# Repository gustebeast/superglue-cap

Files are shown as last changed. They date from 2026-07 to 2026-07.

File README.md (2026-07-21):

# superglue-cap

Parametric replacement **dispenser nozzle + sealing cap** for superglue
bottles, modelled in [CadQuery](https://cadquery.readthedocs.io/) with the
shared [`cadkit`](https://github.com/gustebeast/cadkit) utilities (vendored
under `cadkit/` via git subtree).

The stock dispenser tips on cyanoacrylate bottles clog and shear off; this
replaces them with a printable two-piece set:

- **Nozzle** (~50 mm tall) — screws onto the bottle's neck thread and
  funnels glue through a single continuous internal cone (Ø7.3 throat →
  Ø0.8 orifice, no kinks for glue to pool in) to a slender dispensing tip.
- **Cap** — a 1.6 mm conical shell that follows the nozzle. It closes in a
  **half turn** (2-start, 8 mm lead thread), its flat mouth rim lands on the
  nozzle's flat shoulder, and a 45° internal pocket wedges onto the nozzle's
  tip rim with 0.15 mm of preload — thread torque loads both contacts.

Two bottle variants share all of the code and the same cap — only the
bottle-thread socket differs:

| Variant | Socket bore | Ridge-tip ID | Pitch | Engagement | Status |
|---|---|---|---|---|---|
| `macbeath` | Ø15.3 | Ø13.7 | 2 mm | 11.5 mm | print-validated |
| `loctite`  | Ø18.0 | Ø16.0 | 3 mm | 11.0 mm | fit pending — print its coupon first |

Adding a bottle = adding one `BottleSpec` line in `src/dimensions.py` — or
just using the web generator below with your own measurements.

## Web generator

[`docs/`](docs/) is a browser-based generator (same idea as the
[pantorouter template generator](https://github.com/gustebeast/pantorouter-template-generator)):
measure your bottle's thread with calipers — the page has diagrams for each
measurement — hit Generate, and download STEP/STL for a nozzle, cap, and
thread-fit test piece matched to your bottle. All geometry is built locally in the
browser via [replicad](https://replicad.xyz); nothing is uploaded. The JS
geometry mirrors `src/` constant-for-constant — keep them in sync.

To preview locally (a real HTTP server is needed for the WASM kernel):

```sh
py -3.12 -m http.server 8080 -d docs
# open http://localhost:8080
```

To publish: enable GitHub Pages for the repo, source "main branch /docs".

## Printing

All parts: **flat mouth face down, axis vertical, no supports.**
PETG or PLA, 0.4 mm nozzle, 0.2 mm layers, 3+ walls. Enable your slicer's
elephant-foot compensation (the bottoms are deliberately square for bed
adhesion, and thread ridges reach the first layer). The Ø0.8 orifice prints
tight at 0.4 mm — clear it with a pin, or slice the nozzle at 0.2 mm.

Print the `test_<variant>_socket.step` **coupon** (a few minutes of plastic)
and spin it onto your bottle before committing to the full nozzle.

Note: cyanoacrylate bonds PETG/PLA, so treat the nozzle as a consumable —
or print it in PP, which CA barely sticks to. A PTFE dry-film spray in the
channel makes cured clogs removable.

## Building from source

Requires Python 3.10–3.12 with `cadquery` installed.

```
py -3.12 -m src.build              # all STEPs + assembly.step (+ FreeCAD viewer)
py -3.12 -m src.build --list      # part names
py -3.12 -m src.build --part cap  # one part
py -3.12 -m tools.check_overlaps  # collision gate (0 = clean)
```

`View Assembly.cmd` opens the last-built assembly in FreeCAD (Windows).

## Layout

```
src/
  dimensions.py    every constant + the BottleSpec variants (start here)
  thread_socket.py the asymmetric (buttress) bottle-thread socket + probes
  nozzle.py        nozzle builder (per BottleSpec)
  cap.py           the shared cap builder
  grip.py          grip-rib helper
  build.py         build/export/assembly entry point
tools/
  check_overlaps.py  interpenetration gate over the seated assembly
cadkit/            vendored shared library (threads, export, viewer, ...)
```

Two thread systems live here, and both are probe-gated at build time (a
solid/void march along each helix — OCCT fails silently, so the build fails
loudly instead):

- the **bottle socket** is a project-local asymmetric profile — a 45°
  self-supporting ridge underside with a steep top flank — because these
  bottles' depth-to-pitch ratios are impossible for a symmetric 45° FDM
  thread;
- the **nozzle↔cap** joint uses `cadkit.threads`' multistart family
  (upstreamed from this project), the print-proven Ø13/Ø11 profile on two
  8 mm-lead helices.

## License

[CERN-OHL-S v2](https://cern-ohl.web.cern.ch/) (strongly reciprocal) —
models, code, and site. Use, modify, and sell freely; distribute sources
of derivatives under the same licence.

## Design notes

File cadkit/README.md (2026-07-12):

# cadkit

Small, project-agnostic helpers for **parametric 3D-printing with CadQuery** — the
shared code behind a set of printable-hardware projects. Vendored into each project via
`git subtree`, so every project repo stays self-contained.

## Layout

```
cadkit/
  fasteners.py       M2/M4 hole + heat-set-insert geometry (self-tap now, insert later);
                     one FastenerSpec API, print-undersize aware
  threads.py         self-supporting 45° FDM screw threads (read THREADS_README.md first)
  joinery.py         printable mortise-and-tenon slide joints (read JOINERY_README.md)
  step_export.py     export_step(obj, path) — names the STEP product after the file
  overlap_check.py   parallel interpenetration gate (wrap in tools/check_overlaps.py)
  cq_colors.py       hex / 0..255 / name -> cq.Color, for baking colours into a STEP
  freecad/           OPTIONAL FreeCAD viewer hub (isolated so the core needs no FreeCAD)
    __init__.py        `from cadkit.freecad import show`
  tools/
    agent_sync.py    dev-only multi-agent git-worktree coordination CLI (run as a script)
```

The **core** modules depend only on CadQuery/OCP — no FreeCAD. The FreeCAD-specific
viewer lives in `cadkit.freecad` and is opt-in; `show()` never raises, so viewer trouble
can't break a build.

## Use

```python
from cadkit.fasteners import cut_anchor, M2, M4
from cadkit.threads import cut_thread, threaded_rod
from cadkit.joinery import arrow_tenon, arrow_mortise
from cadkit.step_export import export_step
from cadkit.overlap_check import run
from cadkit import cq_colors
from cadkit.freecad import show          # optional; opens/refreshes a FreeCAD viewer tab
```

A project vendors cadkit at its repo root and runs its build via `python -m` from there,
so `cadkit` is importable with no path hack.

## Vendoring into a project

```
git remote add cadkit https://github.com/gustebeast/cadkit
git subtree add  --prefix=cadkit cadkit main --squash    # first time
git subtree pull --prefix=cadkit cadkit main --squash    # to update later
```

## Changing cadkit — you MUST propagate to every consumer

cadkit is **vendored** (copied) into each project, so the copies **drift** the
moment the canonical repo changes — nothing forces them identical. Therefore a
cadkit change is not *done* when you commit it; it is done when every consumer
project has been re-pulled. **Never edit a project's vendored `cadkit/` in place** —
edit the canonical repo, then propagate.

The whole process is one command — **run it from the standalone canonical cadkit
checkout, after committing your change there** (it refuses to run from a project's
vendored copy):

```
py -3.12 tools/propagate.py        # pushes canonical, then re-pulls into every consumer
```

It pushes the canonical to its upstream (one source of truth), auto-discovers
every sibling project that vendors cadkit, and re-pulls the subtree into each.
A project with a **dirty** working tree is **skipped** (never auto-stashed) and
reported — commit or stash there, then re-run. The exit code is the number of
consumers *not* in sync, so `propagate.py` doubles as a gate: **0 means every
project is current.** Use `--dry-run` to preview, `--no-push` to pull only.

(The manual equivalent, per project, is `git fetch cadkit main &&
git subtree pull --prefix=cadkit cadkit main --squash` — but do not hand-run it
across N repos; that is exactly the step people forget, which is what drift is.)

See `THREADS_README.md` and `JOINERY_README.md` before changing threads or joinery —
both encode FDM-specific rules that fail silently if broken.

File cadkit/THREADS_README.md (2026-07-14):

# `threads.py` — self-supporting 45° screw threads in CadQuery, the reliable way

Cutting a printable helical thread in CadQuery / OpenCASCADE (OCCT) is a known
pain — the kernel fails **silently and weirdly**, returning a smooth cylinder, a
half-filled rod, zero solids, or hanging for minutes, all with *no error*. This
module encodes every workaround we had to find. Import it and move on with your
life; read this if you need to change it.

```python
from cadkit.threads import threaded_rod, cut_thread

# short rods / nut cutters / test coupons:
nut_cutter = threaded_rod(minor_d=11, major_d=13, pitch=4, length=20)
piston = body.cut(nut_cutter)               # -> internal thread in the bore

# a long screw: build a SMOOTH blank, subtract the thread LAST, mill any flat AFTER:
blank = crest_cyl.union(shaft).union(head)  # all smooth
screw = cut_thread(blank, minor_d=11, major_d=13, pitch=4, length=146, z=64)
screw = screw.cut(flat_box)                 # flat AFTER the thread
```

## What the thread looks like

A single-start **45° trapezoidal** thread — symmetric flanks at 45°, with small
flats at the crest and root:

- **Self-supporting.** Because no flank exceeds 45°, an internal thread (a nut)
  prints with its **axis vertical** and needs *no support* in the bore. The screw
  side-prints cleanly too. This is the standard FDM "self-supporting thread".
- **Depth ≤ pitch/2.** 45° flanks need `(major-minor)/2 ≤ pitch/2`. E.g. pitch 4 →
  depth ≤ 2; we run Ø13/Ø11 = depth 1.0 with 1.0 mm flats for margin.
- **Cut, never grown.** The thread is helical **valleys cut out of a solid
  crest-diameter blank**. Do *not* build a thread ridge and union it onto a core —
  OCCT drops the core and you get a hollow spring that still reports `solids == 1`.

## Sideways (horizontal-axis) female threads — `teardrop_thread_cutter`

A female thread whose axis prints **horizontal** (a screw hole in a part that lies flat
on the bed) can't use a plain round bore: the bore's top arc is an unsupported overhang
that **sags into a rough, tight thread**. `teardrop_thread_cutter` is the cutter to
subtract for any horizontally-printed threaded hole. **Print-tested clean** (Ø6 cap
screw, PETG — see the clearance table). Orient the part so **print-up is +Y**.

It returns a threaded rod **unioned** with a self-supporting **hexagon peak** on its +Y
side — subtract it, then `clean=False` / don't heal (same thread rules):

```python
from threads import teardrop_thread_cutter
cutter = teardrop_thread_cutter(minor_d, major_d, pitch, engage_len,
                                z=z0, peak_h=..., over_lo=0.0)   # blind end flush
part = part.cut(cutter.translate((x, y, 0)), clean=False)
```

- **Keep the FULL round bore — never slice its top off.** A round screw needs that top;
  a secant/gable cut that removes it leaves solid material where the screw's upper half
  must go and the screw won't seat. The peak is *added* above the full bore, not carved
  out of it. (Cost a build to learn — the "gable" looked right and blocked the screw.)
- **The peak is a HEXAGON, not a plain teardrop.** The transition from round threads to
  the smooth attic runs on **45° planes** (the lines `y = ±x`, matching the thread's 45°
  flank), so the top-wedge ridges are cut **clean**. A horizontal base (plain
  trapezoid/teardrop) slices each tooth on a flat → thin sub-nozzle **slivers**. The
  hexagon's left/right corners (a +45° meeting a −45° edge) are 90°.
- The round lower ~270° stays threaded; the top ~90° is given up to the peak (same trade
  as the drive screw's milled flat). It grips fine.
- `peak_h` truncates the tip to a short flat **bridge** when the wall above the hole is
  thin (a small sag on a <2 mm bridge is harmless). `over_lo`/`over_hi` set the peak
  overshoot per end: **keep it at the MOUTH** (opens the teardrop cleanly where the
  socket exits into air), **zero it at a BLIND end** — else the hexagon drills a pocket
  deeper than the round bore and you get two visible hole depths.
- The thread **runs out** at each end through `threaded_rod`'s conical lead-in, so the
  last tooth dissolves into a smooth cone instead of a thin feather — don't "fix" it.

## Multi-start (quarter-turn) threads — `multistart_rod` / `cut_multistart_thread`

A cap that seals in a **90° turn** needs a multi-start thread: `starts` parallel
helices, each advancing `lead = spacing·starts` per turn (4-start × 4 mm spacing →
4 mm per quarter turn). The trick that keeps this inside everything already proven:
**the cross-section derives from `spacing`** (the caliper ridge-to-ridge distance),
so a 4-start spacing-4 thread is locally IDENTICAL to the pitch-4 single-start
profile — only the helix steepens (~24° lead angle at Ø12).

```python
from cadkit.threads import multistart_rod, cut_multistart_thread

# male collar on the nozzle (0.6 mm diametral clearance taken off the male):
nozzle = cut_multistart_thread(smooth_nozzle, minor_d=10.4, major_d=12.4,
                               spacing=4, starts=4, length=6, z=collar_z)
# female nut in the cap (cutter at NOMINAL size):
cap = cap_body.cut(multistart_rod(11, 13, spacing=4, starts=4,
                                  length=6.5, z=-0.5), clean=False)
```

Multi-start-specific rules (each verified by crest probes in `superglue-cap`):

- **Never reuse `thread_segments` for multi-start** — its flats derive from the
  full per-helix pitch; at lead 16 the valleys come out 7 mm wide and the starts
  erase each other. `_valley_profile(minor, major, spacing)` is the shared quad.
- **Different starts must not overlap**: valley width at the overshoot < spacing
  (checked, raises). Same 3.6-vs-4.0 margin as the proven pitch-4 profile.
- **Sweeps are still whole turns — of the LEAD.** A short band (a 6 mm collar on
  a 16 mm lead) is covered by ONE full-turn sweep based at the band and RUNNING
  OUT past it: upward it must exit into air or a sub-minor-Ø section; downward it
  leaves a shallow helical notch (~a groove half-width) in whatever shoulder is
  there — keep that notch inside the mating rim's clearance Ø.
- **Sweeps may pass THROUGH blank faces** (the nut cutter's rod is shorter than
  one lead; the sweeps enter below and exit above it, ending in air). Rule 5's
  killer is a sweep **ending at** a blank face, not passing through one.
- **A healthy N-start thread probes IDENTICALLY at θ and θ+360°/N** (and for even
  N, at θ+180°) — that symmetry is a quick sanity signature, not a bug.
- Self-locking is weak at steep leads (24° > friction angle): a quarter-turn cap
  holds shut by seal friction. If it backs off, add a detent, don't flatten the lead.

First deployment: superglue-cap nozzle↔cap (Ø13/Ø11, spacing 4, 4-start, 0.6 mm
diametral clearance off the male, 0.4 nozzle). **Print-fit pending** — record the
verdict in the clearance table below when it's in.

## Clearance (print-tested)

Thread clearance is print-dependent — nozzle width, layer height, orientation, and
material all change how much slop you need, so **record what you measure**. Tip: when
the nut is already printed, put the clearance on the **screw** side (shrink the screw,
keep the nut cutter fixed) so you only reprint the screw.

Tested combinations (append as you find them):

| thread | clearance (diametral) | nut / socket print | screw print | nozzle | layer | result |
|---|---|---|---|---|---|---|
| Ø13/Ø11, pitch 4, 45°, depth 1.0 | **0.8 mm** (0.4/side) | axis vertical (self-supporting bore) | on its side, on the flat | 0.8 mm | 0.24 mm | threads fast & easy, a bit loose — fine when the nut is well supported in X/Y |
| Ø6/Ø4.4, pitch 3.5, 45°, **teardrop socket** | **0.4 mm** (0.2/side) | **horizontal axis, hexagon peak up** | on its side, on the flat | 0.8 mm | — | **PETG**: turns in/out easily, on the **loose** side — a good friction hold for a cap here; go **0.2–0.3** for a snugger fit on other projects |

## The rules (each one cost a build)

Every violation below is a **silent** failure. The only reliable detector is a
**crest solid/void probe**: march up Z at `r = major/2 - 0.15` and classify
point-in-solid; a real thread alternates `#....#....#`, a broken one is all `#`
(smooth/filled) or throws (0 solids). Never trust the eye or `solids == 1`.

1. **Groove profile must be a 4-point quad.** A 6-point profile (e.g. a "capped"
   valley) makes the swept cutter's `.cut()` wipe the whole part to 0 solids.

2. **Depth ≤ pitch/2**, and keep margin — a valley near `pitch/2` wide, tilted by
   the helix lead angle (isFrenet), self-overlaps turn-to-turn into an invalid
   cutter that no-ops.

3. **A single sweep is clean only to ~100 mm.** Longer, and the sweep+cut wipes the
   part (0 solids). So **tile** the length in short **segments** (`_SEG_LEN = 72`).

4. **Segments must ABUT, never overlap.** Cutting a helix cutter that overlaps an
   already-cut region **silently no-ops** — so every segment after the first leaves
   its span *filled*. (Unioning the overlapping segments into one cutter first fills
   too.) Abut them and **phase-align** each (`rotate 360°·z0/pitch`) so the valleys
   line up into one continuous single-start thread across the seams. Pick a segment
   length that's a multiple of the pitch so the joins land on a tooth edge (phase 0).

5. **Sweep height AND blank height must be whole turns** (multiples of pitch). A
   *partial* final turn wipes the part; so does a sweep that reaches the top of a
   non-whole-turn cylinder. `threaded_rod` rounds its rod **up** to a whole turn;
   `cut_thread` rounds the span **down** so the thread ends *inside* the blank —
   overshooting up into a smaller-Ø shaft grazes it and leaves a thin degenerate
   face at the thread top (a visible "rectangle" artifact).

6. **Cut the thread LAST and ALONE.** Every boolean on the finished (many-face)
   thread is slow — unions/cuts that took ~6 s on a smooth blank *hung for minutes*
   on the thread. So build the whole smooth blank (crest rod + shaft + head) first,
   subtract the thread, and mill the **flat after** the thread (flat-before-thread
   makes the full-helix cutter overlap the flat's void → no-op → filled thread).

7. **`clean=False` on every thread boolean, and never `heal()`/ShapeFix a threaded
   part.** CadQuery's default post-boolean unify (`ShapeUpgrade_UnifySameDomain`)
   and OCCT's `ShapeFix` both crash or hang on the many-face helix. The un-unified
   solid exports to STEP and slices fine.

## Debugging approach (reuse these)

When a thread change misbehaves, don't stare at the render — **probe**. The scratch
scripts that cracked this (kept in the session scratchpad) were:

- **crest probe** — march up Z at the crest radius, print `#`/`.`; catches
  smooth/filled/partial instantly. **Probe OFF the θ=0 seam plane** (e.g. at
  θ=90°/270°): the helix start/end profile faces lie exactly in y=0, and
  `BRepClass3d_SolidClassifier` reports those boundary faces as not-inside —
  a healthy thread reads broken there (cost a debug session in superglue-cap).
- **height matrix** — sweep single cuts at heights 12…150 and at cylinder-vs-sweep
  height combos; this is how the ~100 mm limit and the whole-turn rule surfaced.
- **min-wall / distance probes** (`BRepClass3d_SolidClassifier`,
  `BRepExtrema_DistShapeShape`) for rims and clearances.

## Prior art

This matches long-standing CadQuery/OCCT reports — the "silent empty result on
helix boolean" and "split the helix into <360° segments" advice:
- <https://github.com/CadQuery/cadquery/issues/1328>
- <https://github.com/CadQuery/cadquery/issues/595>
- <https://github.com/CadQuery/cadquery/issues/407>

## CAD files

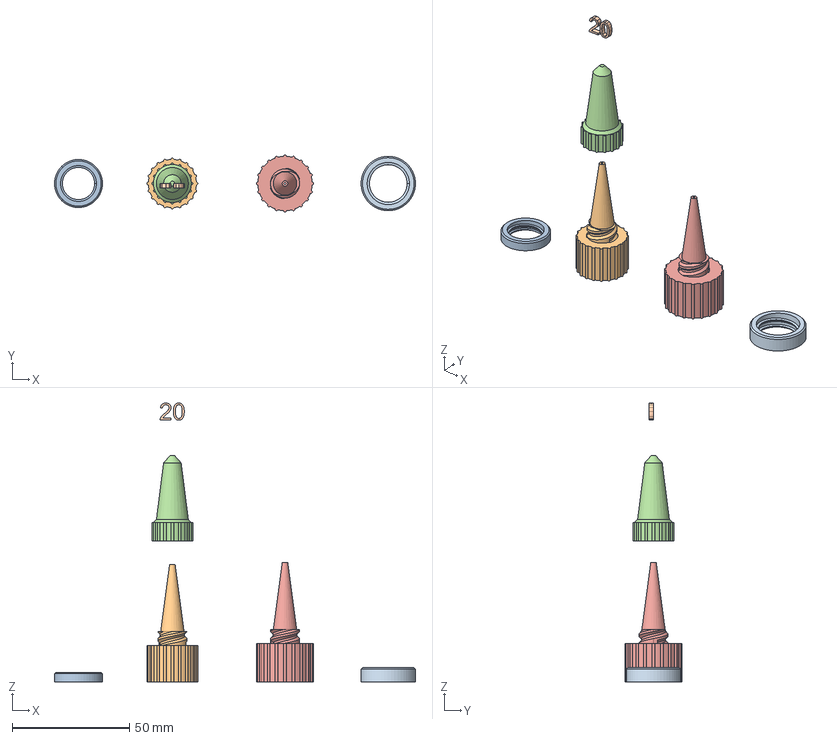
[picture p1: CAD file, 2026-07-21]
assembly.step
153.8 x 24.4 x 118.9 mm
nozzle_macbeath
cap
nozzle_loctite
macbeath_coupon
loctite_coupon
build_counter

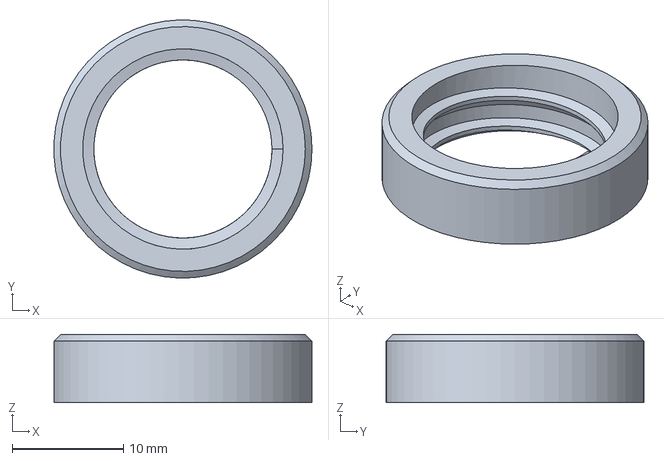
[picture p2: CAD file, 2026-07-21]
test_loctite_socket.step
23.2 x 23.2 x 6.12 mm

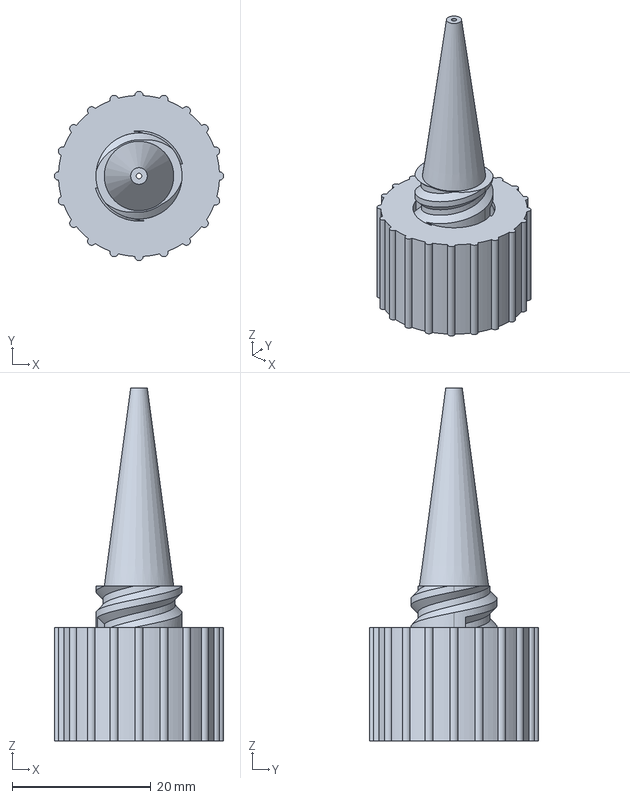
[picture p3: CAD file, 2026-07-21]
nozzle_loctite.step
24.4 x 24.4 x 50.9 mm

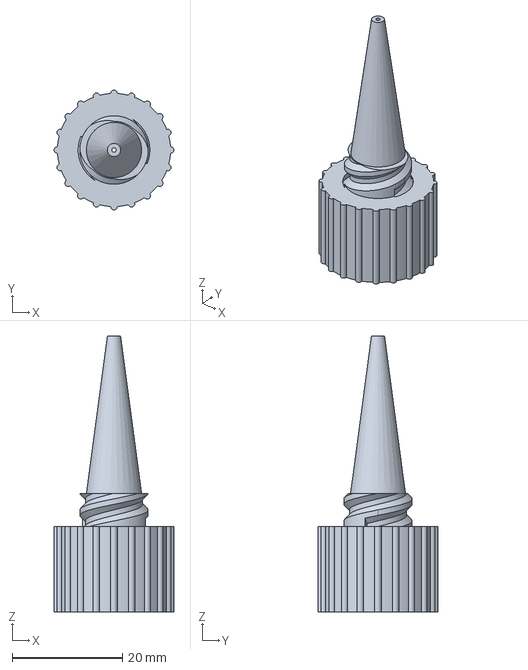
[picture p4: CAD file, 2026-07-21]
nozzle_macbeath.step
21.7 x 21.7 x 50.0 mm

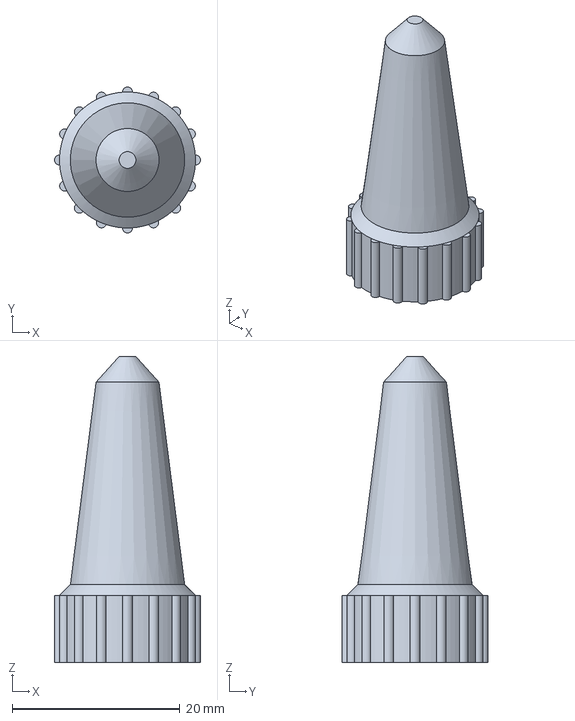
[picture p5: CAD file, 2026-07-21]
cap.step
17.4 x 17.4 x 36.5 mm

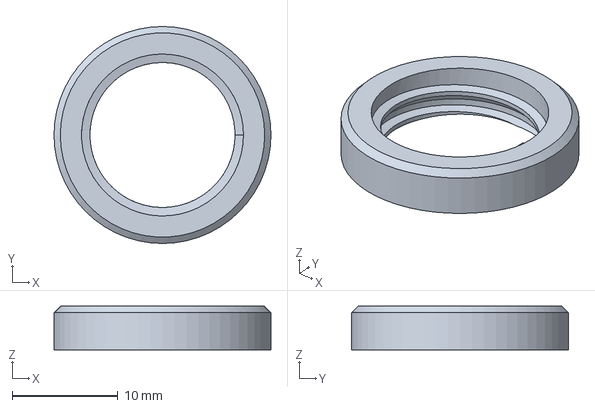
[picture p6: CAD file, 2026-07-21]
test_macbeath_socket.step
20.5 x 20.5 x 4.12 mm

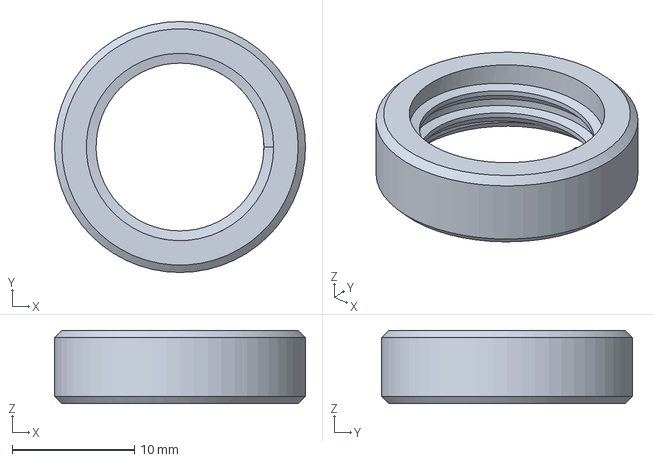
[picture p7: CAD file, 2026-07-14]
test_bottle_socket.step
20.5 x 20.5 x 6.00 mm

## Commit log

2026-07-12 Thread-fit coupon: asymmetric female socket for the bottle neck
    Bottle measured: Ø13 major / pitch 2 / depth 1 / single start / 2 turns.
    Symmetric 45° (cadkit.threads) is impossible at that pitch+depth, so
    src/thread_socket.py cuts a buttress-style profile: 45° ridge underside
    (self-supporting, mouth-down print), 15° top flank, tip at Ø12 for 0.5mm
    flank engagement. Coupon + future cap share socket_cutter(); build probes
    the ridge band solid/void (off the helix seam) and fails on a silent
    OCCT no-op.
    [assembly.step, test_bottle_socket.step]
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2026-07-13 Coupon v2: scale socket to bore Ø15.3 / tip Ø13.7 (0.8mm thread)
    v1 was undersized on the real bottle; socket dims are now user-specified
    directly and the stale BOTTLE_* asserts are retired until re-measure.
    [assembly.step, test_bottle_socket.step]
2026-07-13 Cap: solid 45° conical roof over the validated socket
    11.5mm of threaded vertical wall (old cap's interior depth), interior
    ceiling closes as a 45° cone (self-supporting mouth-down), exterior
    follows as a 45° cone truncated to a Ø3 flat. Socket geometry is the
    print-validated socket_cutter() shared with the coupon; fit verdict
    recorded in dimensions.py.
    [assembly.step, cap.step, test_bottle_socket.step]
2026-07-13 Cap threads run the full vertical wall (5 whole turns)
    Turn count is now a socket_cutter() parameter: the coupon keeps its
    validated 2 turns, the cap fits as many whole turns as its 11.5mm wall
    allows above the entry lead (5 turns, thread top 0.3 under the ceiling).
    [assembly.step, cap.step, test_bottle_socket.step]
2026-07-13 Split into nozzle + sealing cap; cadkit.threads for the collar joint
    nozzle.step: validated bottle socket (skirt Ø20.5), 45° shoulder, male
    collar Ø12.4/Ø10.4 pitch 4 (cut_thread; 0.6 diametral clearance taken
    off the male per the shrink-the-screw convention), Ø9→Ø4 dispensing
    cone with a Ø2 glue channel.
    cap.step: female Ø13/Ø11 pitch-4 nut (threaded_rod cutter, nominal),
    cavity hugging the cone at 0.5/side, 45° seal pocket the Ø4 tip rim
    wedges into with 0.3mm preload — torque loads the seal, not a shoulder.
    All three threads probed; overlap gate whitelists the seated cap↔nozzle
    contact.
    [assembly.step, cap.step, nozzle.step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]
2026-07-13 Straight ribbed barrel, internal cone to Ø0.8, flat-on-flat seal, grip ribs
    The dispenser cone moves INSIDE: the barrel is a straight Ø8 cylinder
    (the outside cone left an awkward tapered gap under the cap) and the
    glue channel tapers from a Ø5 throat to a Ø0.8 orifice at the flat tip
    face. The cap's seal pocket becomes a flat ceiling 0.3mm proud of the
    seated tip plane — a clean flat-on-flat contact loaded by thread
    torque. Both pieces get 20/16 vertical Ø1.2 grip ribs (src/grip.py),
    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
    [assembly.step, cap.step, nozzle.step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]
2026-07-14 Flat shoulder for the cap rim; dispensing cone tip restored
    The skirt->collar transition is a flat annular step (the highlighted
    45-degree shoulder cone left a gap under the cap's flat mouth rim) and
    the exterior dispensing cone returns (O9->O4, internal taper to the
    O0.8 orifice kept). Seal preload drops to 0.15 so the tip pocket and
    the flat mouth-shoulder contact engage together.
    [assembly.step, cap.step, nozzle.step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]
2026-07-14 Quarter-turn cap thread (4-start, 16mm lead); 50mm continuous-cone dispenser
    src/quick_thread.py sweeps the print-proven pitch-4 cross-section
    (depth 1, 1mm flats, 45 deg flanks, ridges 4mm apart) along 4 helices
    at 16mm lead - 90 deg of rotation advances 4mm, from caught to sealed.
    Collar shrinks to 6mm; same 0.6 diametral clearance off the male.
    The dispenser is 50mm tall with ONE continuous internal cone (O7.3 at
    the shoulder plane -> O0.8 orifice, ~6 deg) running unbroken through
    the collar and cone - the old mid-channel kink at O5 is gone. Shoulder
    raised to 15.5 so the collar keeps 1.55mm of wall over the channel.
    Exterior cone O10 -> O3 tip.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
    [assembly.step, cap.step, nozzle.step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]
2026-07-14 Tip wall 1.1 -> 0.8mm (tip OD O3 -> O2.4); seal pocket rebased
    Pocket base widened to tip+1.9 so the cap cavity keeps clearing the
    cone right up to the pocket; contact circle now O2.4, same 0.15
    preload.
    [assembly.step, cap.step, nozzle.step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]
2026-07-14 Cap slimmed to a 1.6mm shell that follows the dispensing cone
    Exterior is one revolved profile: chamfered mouth, O16.2 thread boss
    (threads + ribs grow outward from the shell), 45-degree blend onto a
    shell cone tracking the cavity at CAP_WALL=1.6, top cone closing with
    1.6 of solid over the seal pocket (pocket ceiling now a O1.4 flat
    instead of a needle apex). Ribs sit on the boss only.
    [assembly.step, cap.step, nozzle.step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]
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2026-07-14 Use cadkit.threads multistart API; retire src/quick_thread.py
    The quarter-turn thread was upstreamed into canonical cadkit
    (multistart_rod / cut_multistart_thread) and propagated back in via
    the subtree. Probe patterns are identical to the local implementation.
    [assembly.step, cap.step, nozzle.step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]
2026-07-14 Two bottle variants (macbeath + loctite); half-turn cap thread
    BottleSpec parameterizes the socket (bore/tip/pitch/engagement); the
    dispenser above the flat shoulder is identical for all variants, so ONE
    cap fits every nozzle. macbeath = the validated original (O15.3/O13.7,
    pitch 2, 11.5mm); loctite = O18/O16, pitch 3, 11mm - fit PENDING, print
    test_loctite_socket.step first. Renames: nozzle.step ->
    nozzle_macbeath.step, test_bottle_socket.step -> test_macbeath_socket.step.
    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
    [assembly.step, cap.step, nozzle_loctite.step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]
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2026-07-14 Raise socket thread entry so ridges touch the wall over their full path
    The first ridge's 45-degree underside extends ~valley_drop below its
    helix start; with entry at 1.2 that landed inside the mouth-chamfer
    flare, leaving the ridge edge detached from the wall (floating fin).
    entry_lead is now per-spec: chamfer + valley_drop + 0.2 margin
    (macbeath 2.25 -> 4 turns, loctite 2.45 -> 2 turns), with a new assert
    that the last ridge's top flank also stays below the ceiling.
    [assembly.step, cap.step, nozzle_loctite.step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]
2026-07-14 Flat bottoms for bed adhesion; ribs run down to the bed
    Bottom 0.6 chamfers removed everywhere (nozzle skirt, cap profile,
    coupon bottoms - coupons keep a top chamfer only). Grip ribs now start
    at z=0 with flat bottoms, adding first-layer area; add_grip_ribs keeps
    the 45-degree bottom chamfer only when a rib is elevated. Elephant's
    foot is the slicer's job now (enable compensation).
    [assembly.step, cap.step, nozzle.step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]
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2026-07-21 Code-quality pass for publishing: stale docs, dead refs, README
    Three review passes with regression builds between (probe patterns
    byte-identical, gate clean):
    - fixed stale docstrings/comments (quarter-turn -> half-turn, chamfered
    mouths that are now flat, references to removed geometry like the
    nut entry bevel and the solid cap)
    - removed duplicate local math imports; lambda helpers -> named defs
    - cap interior stack expressed via NUT_OVER instead of a -0.5/+0.5 dance
    - build.py: nozzles built from BOTTLES as a dict (scales with variants),
    probe loop deduplicated, unused LOCTITE import dropped, part notes
    made consistent
    - added README.md (overview, variant table, print settings, b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
    [assembly.step, cap.step, nozzle_loctite.step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]
2026-07-21 Browser-based generator (docs/): measure your bottle, generate, print
    Static replicad + three.js site modeled on the pantorouter template
    generator: caliper measurements (thread OD, root O, pitch, cap depth -
    each with an SVG diagram), a fit-clearance knob, Generate -> live 3D
    preview + STEP/STL downloads for a matched nozzle, the shared cap, and
    a thread-fit coupon. Defaults regenerate the validated macbeath socket
    exactly. Geometry is a line-for-line port of src/ (helical sweeps via
    makeHelix + frenet genericSweep; flip-proof 3D profile wires; stacked
    cone-extrudes instead of revolve). Includes care guidance: dry-lube
    the channel (CA sticks to printed parts), and after gluing hold the
    bott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
2026-07-21 Tighten the site subtitle
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
